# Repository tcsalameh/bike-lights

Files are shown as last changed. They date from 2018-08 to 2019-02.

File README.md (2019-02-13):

## Speed-sensitive bike lights

This is a project I did to create side-mounted lights for my commuter bike that would react to different speeds.

You can see them in action in the short video below!

video (https://www.youtube.com/watch?v=7HX3JH0OVps)

## Hardware Design

An LED light strip covers both sides of the bike, going up the downtube (the bottom part of the frame), around the front of the headtube (the front part of the frame above the wheel), and back down the downtube on the other side.

The computer (an Arduino Uno) and battery sit inside a re-purposed water bottle container attached to the seat tube (the middle part of the frame). A [Hall sensor chip](https://en.wikipedia.org/wiki/Hall_effect_sensor) installed on one of the seat stays (the back lower part of the frame) records whenever a magnet attached to one of the spokes passes by. The computer uses this data to measure speed, so it can determine what to display on the light strip.

I also wanted to be able to easily detach the whole system from my bike, in about 5 minutes or less. The light strip and sensor cabling can detach from the power/computer container, and the whole system is secured with velcro to the frame. I've been able to take it on and off, and even stick it in a backpack, without too much trouble.

Battery life is quite long.
From the numbers [here](https://learn.adafruit.com/battery-power-for-led-pixels-and-strips/estimating-running-time), each "pixel" of 3 LEDs has a max power consumption of 60 mAh.
I guessed the battery pack had approximately 3000-4000 mAh based on https://en.wikipedia.org/wiki/AA_battery#Rechargeable_cells.
Eight pixels are on at a time, so even if they were running at max brightness, I would expect something in the range of 5-7 hours battery life, taking extra power needed for the other components into account.
The pixels are typically nowhere near the max brightness, so this might even be a low estimate.
Empirically, I've been able to leave it on for hours at a time with no visible effect on LED brightness.

The battery capacity is far more than I need. If I were to make another iteration, I would look at 3d printing the case and select a smaller form factor for the computer and power supply.
I would also rethink the placement of the cables, the velcro system (would be nice not to have to glue velcro to the frame), and the minimal protection from the elements.

## Software Design

I kept this project simple, with less than 300 lines of code.
However, I have plans to experiment with external graphical interfaces to simulate and update the system, which would make it a lot more complex.

The Arduino Uno is a single-threaded, single core computing platform that just runs the code you provide in a tight loop over and over.
This posed a challenge for simultaneously keeping track of the speed and updating the light strip.
Although the Arduino Uno does not have genuine threads, you can use a number of pseudo-threading libraries (I used [ArduinoThread](https://github.com/ivanseidel/ArduinoThread)). These give the appearance of multi-tasking by only executing the work given to the thread at a set interval, and doing a no-op any other time the thread is called. If you have 2+ tasks that don't have to run on every loop and they do fairly lightweight work, then setting them to run at different intervals, faster than a human would typically notice, can give the appearance of simultaneity.

Updating the light strip and keeping track of the speed fit this use case well. The light strip is idle most of the time except during transition, and it isn't crucial that we calculate the speed at every millisecond. I implemented two pseudo-threads running callbacks on separate time intervals: A light strip updating thread, and a speed updating thread. I discovered it was important to execute the actual sensor reads in every loop, because it is easy to miss a read at high speed. So, that action occurs outside of the thread context in loop().

I also wanted the speed data to inform the frequency of the light strip update operation. This turned out to be fairly simple: The light strip thread gets the latest speed from the speed thread, and then updates its own callback frequency based on this data.

Lastly, I had fun working out different ways to change the lightstrip along color gradients. I ended up settling on a linear gradient to move between RGB values, but I'm sure there are all kinds of other interesting algorithms to explore (maybe I should study some color theory!).

## Parts

- 1 Arduino Uno
- 1 4AA battery holder (https://www.amazon.com/LAMPVPATH-Battery-Connector-Plastic-Housing/dp/B01MAXT00Q/)
- 4 rechargable AA batteries. Note: The rechargable part is important! Alkaline batteries will have a higher voltage. 4AA rechargable is ~4.8V, close enough to 5V to power the whole system without issue. 4AA alkaline is ~6V, above the safe voltage for the light strip.
- 1 toggle switch (https://www.adafruit.com/product/3308)
- 1 Hall sensor chip (https://www.amazon.com/SunFounder-Switch-Sensor-Arduino-Raspberry/dp/B013G5N03O/)
- 1 spoke magnet (https://www.amazon.com/CatEye-Universal-Wheel-Magnet/dp/B018RZ23AE/)
- 1 470-ohm resistor
- 1 large capacitor (I used the 4700uF model found here: https://www.adafruit.com/product/1589)
- 1 Neopixel light strip, 60 pixels per strip (https://www.adafruit.com/product/1461?length=1)
- 2 4-wire waterproof cables (https://www.adafruit.com/product/744)
- 1 mid-size water bottle storage container (or even just a water bottle). Main limiting factor here is whether the Arduino can fit through the mouth of the bottle. I used the WBS Unit from Profile Design, it was just barely big enough to fit everything (https://www.amazon.com/Profile-Designs-Water-Bottle-Storage/dp/B01E6EZNW0/).
- Adhesive velcro strips, and some velcro ties
- Some sticky pads for wall hangings (relevant for padding the sensor if you need to get it closer to the wheel)
- Lots of colored hook up wire, shrink wrap, superglue, etc.

## Wiring Diagram

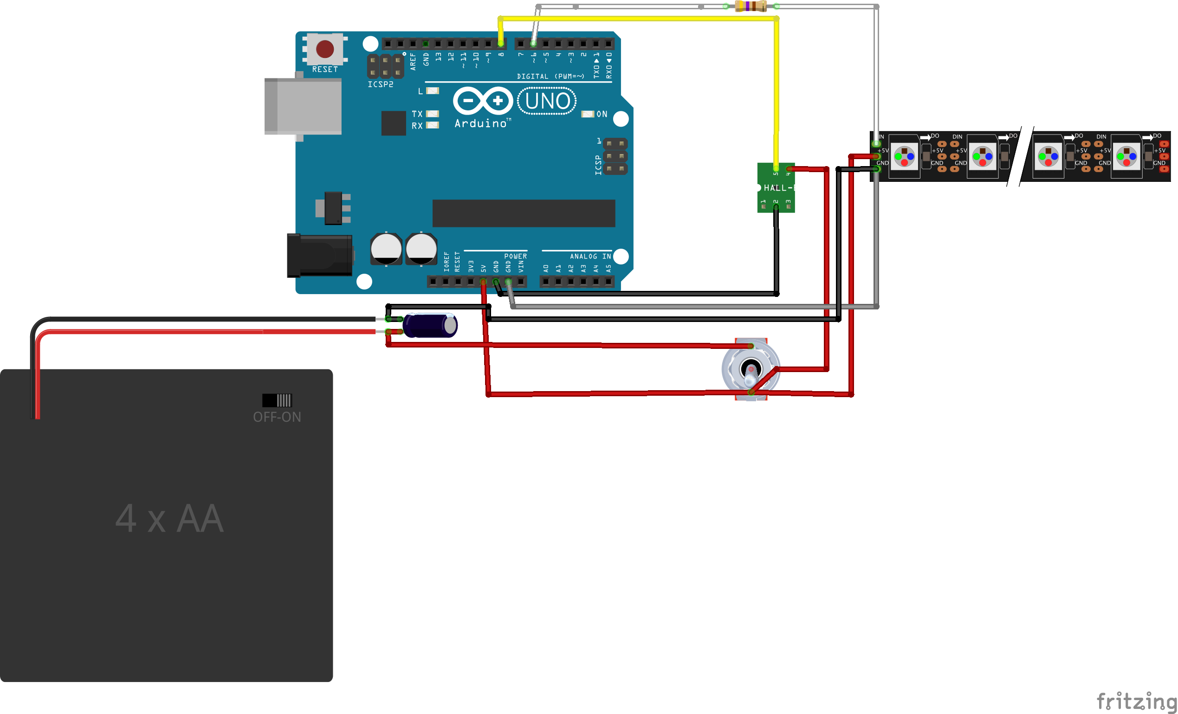
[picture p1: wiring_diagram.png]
Wiring Diagram


## How to make it

1. I wired up and got the whole system working without trying to put anything other than the light strip on the bike. Only after I was satisfied that the code/hardware actually worked, did I think about how it was going to get attached.
1. Then, I took the water bottle storage container and drilled 3 holes - one just above where the cage would end for the toggle switch, and two in the bottom of the container (for cables for the light strip and the Hall sensor).
1. Then, I broke out the soldering iron and started with where the 4 wire cables would end: at the light strip and at the sensor.
      - Soldered the 4 wires to power, data, ground, and ground wires from the LED strip. I lost the threaded connector for the cable during this process.
      - For the other one, cut off one wire and soldered the remaining to power, data, and ground wires of the Hall sensor.
1. Then, I started from the other end and connected the power supply to the toggle switch, and soldered wires going into and out of the switch.
1. At this point I really wanted to be sure that everything was right, because once I soldered any of the 7 wires from the cables to the Arduino or output of the switch, I wouldn't be able to dissasemble anything without de-soldering most of it.
1. After making sure, I soldered all the remaining connections, which was a bit tricky since everything was half in the container. Since the power/ground wires going to the Arduino were so close, I put some glue in between them after soldering the wires to the header pins, as insulation.
1. Then I attempted to stuff everything into the storage container. It took some wrangling, but the container was just barely large enough to fit everything. I'd originally planned to somehow mount the Arduino and battery pack in there to prevent rattling around, but they fit pretty snugly anyhow. The battery pack is easy to remove for recharging, and the USB port on the Arduino is easily accessible for reprogramming.
1. Finally, I worked on mounting the sensor to the back left chainstay, near the wheel. I used a small piece of an adhesive velcro strip to attach it, and found that I needed to put some padding on the back of the sensor to get it close enough to the wheel. Using adhesive wall hanging strips added about 10-20 millimeters, more than enough. I forgot to put a cover over the sensor before attaching the Velcro, so it is exposed to the elements (and I will probably need to replace it). Strategically placed velcro ties keep all the cables from straying too far from the frame.

## More Pictures and Videos

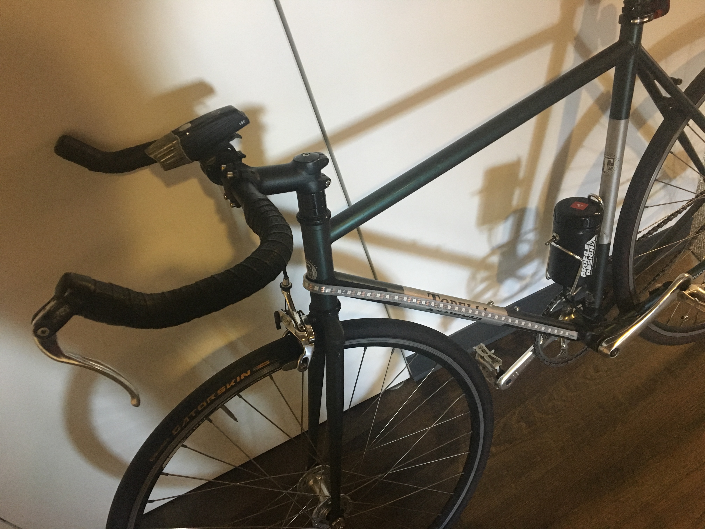
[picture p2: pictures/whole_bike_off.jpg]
bike

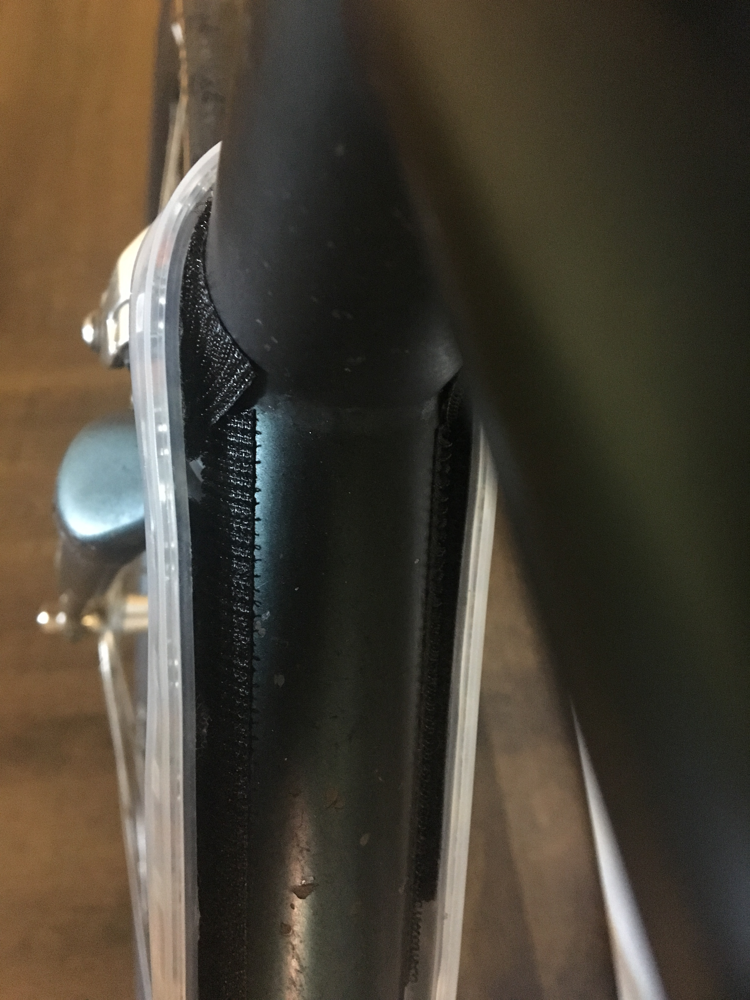
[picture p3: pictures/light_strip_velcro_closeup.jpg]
led_velcro

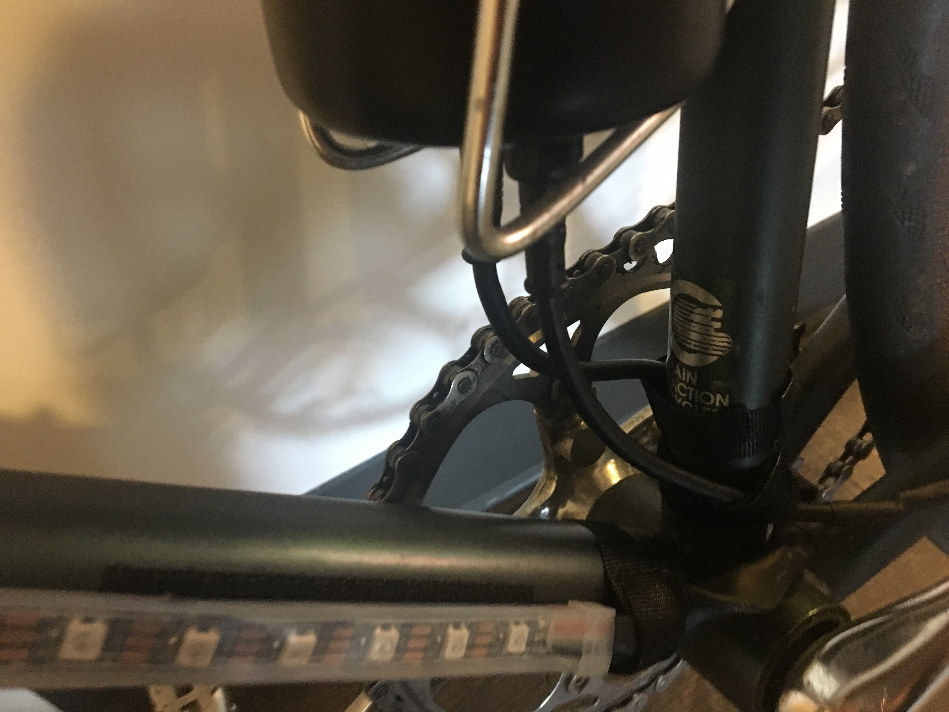
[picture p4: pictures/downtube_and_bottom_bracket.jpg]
downtube_bb

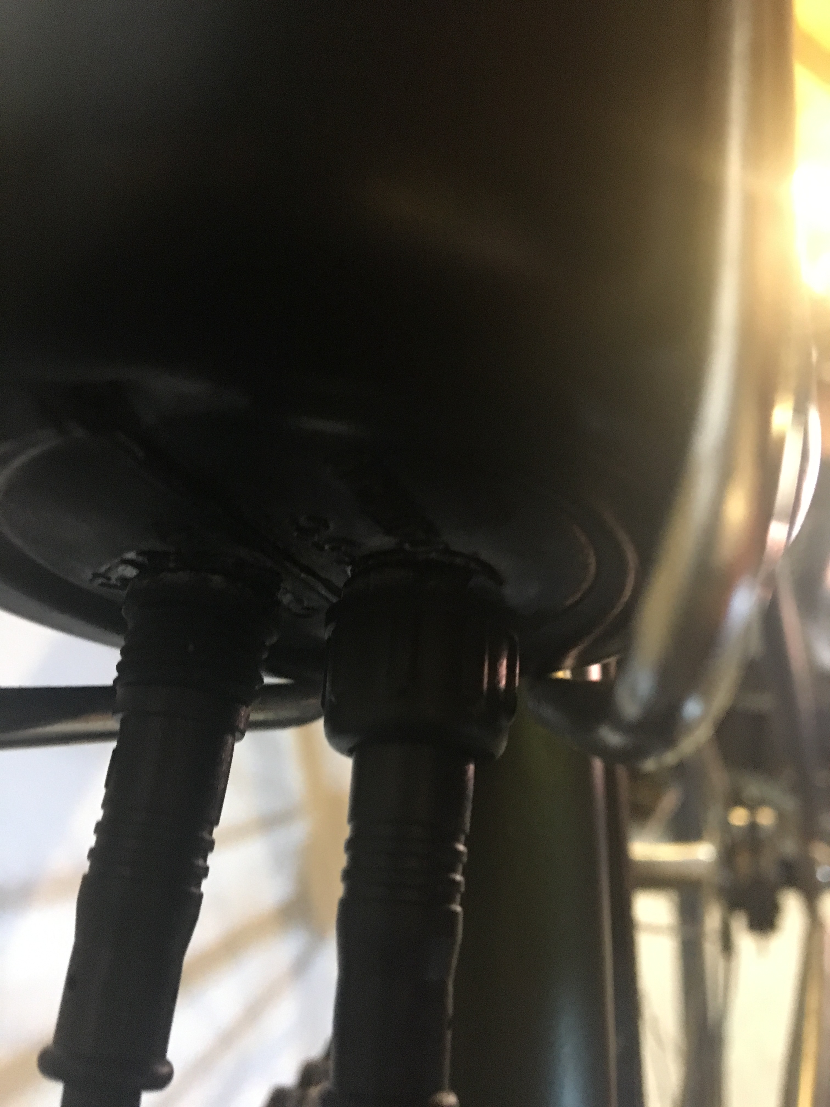
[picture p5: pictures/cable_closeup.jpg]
cable_closeup

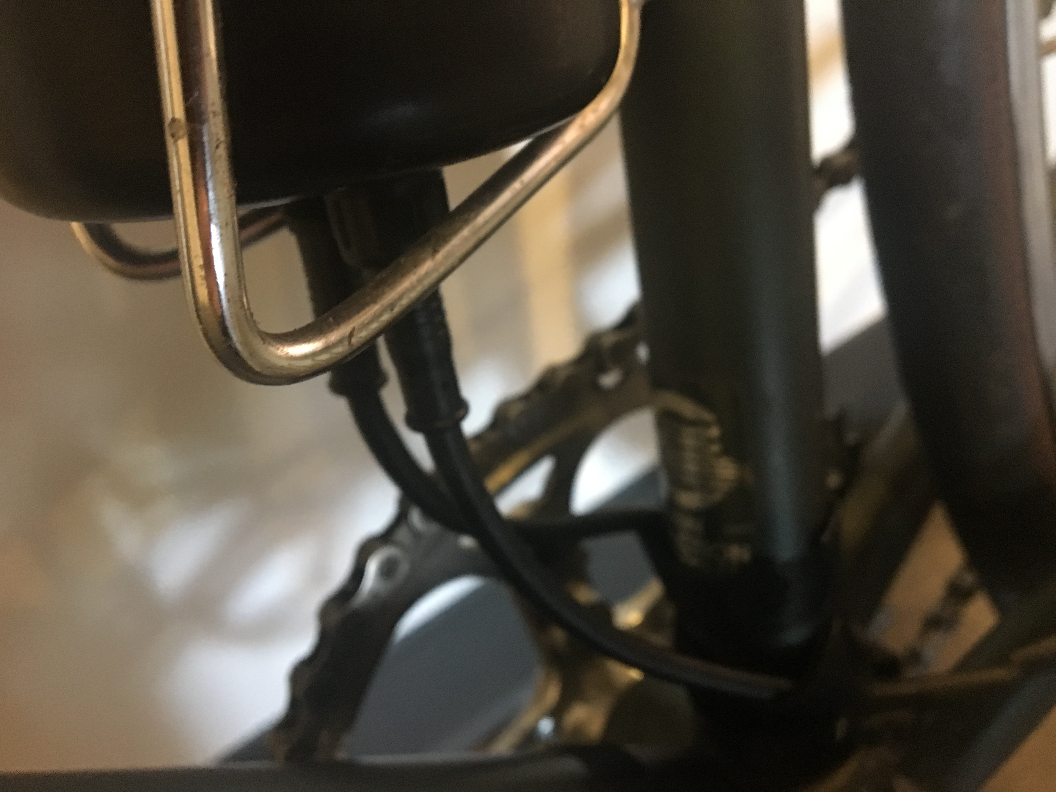
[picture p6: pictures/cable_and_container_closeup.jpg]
cable_and_container_closeup

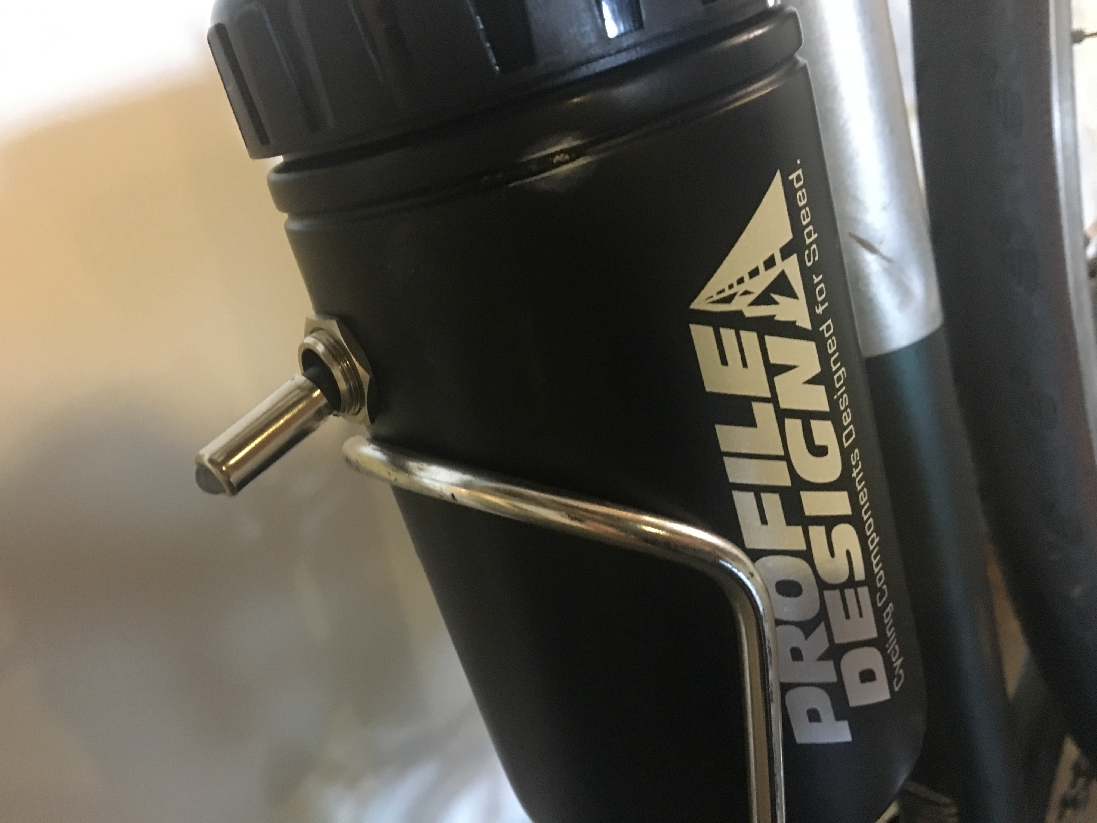
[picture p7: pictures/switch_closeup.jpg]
switch_closeup

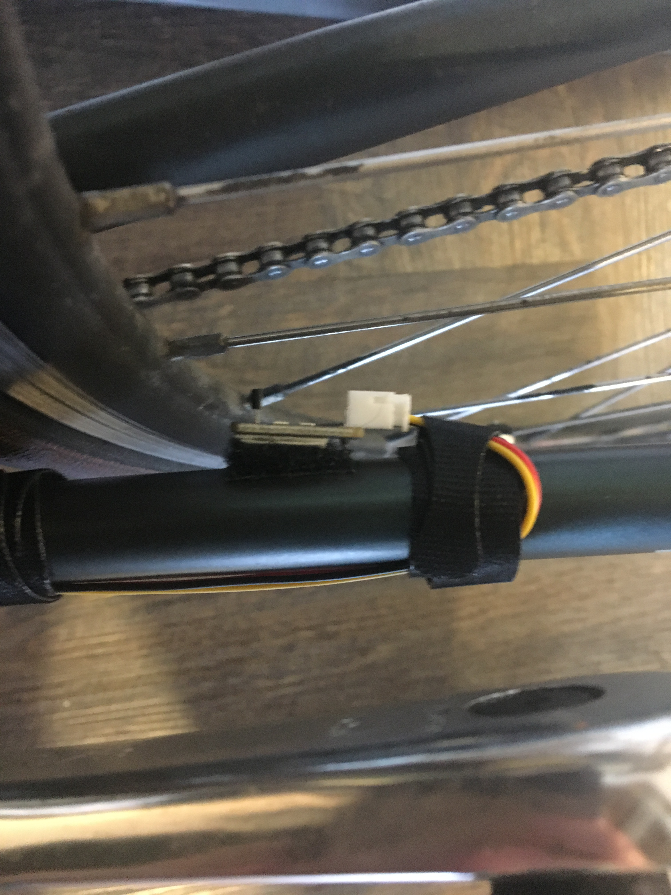
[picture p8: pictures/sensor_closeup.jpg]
sensor_closeup

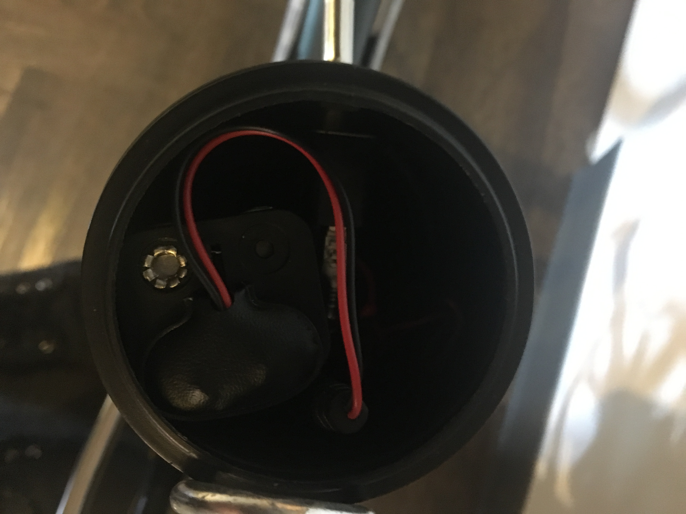
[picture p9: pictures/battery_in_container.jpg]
open_container

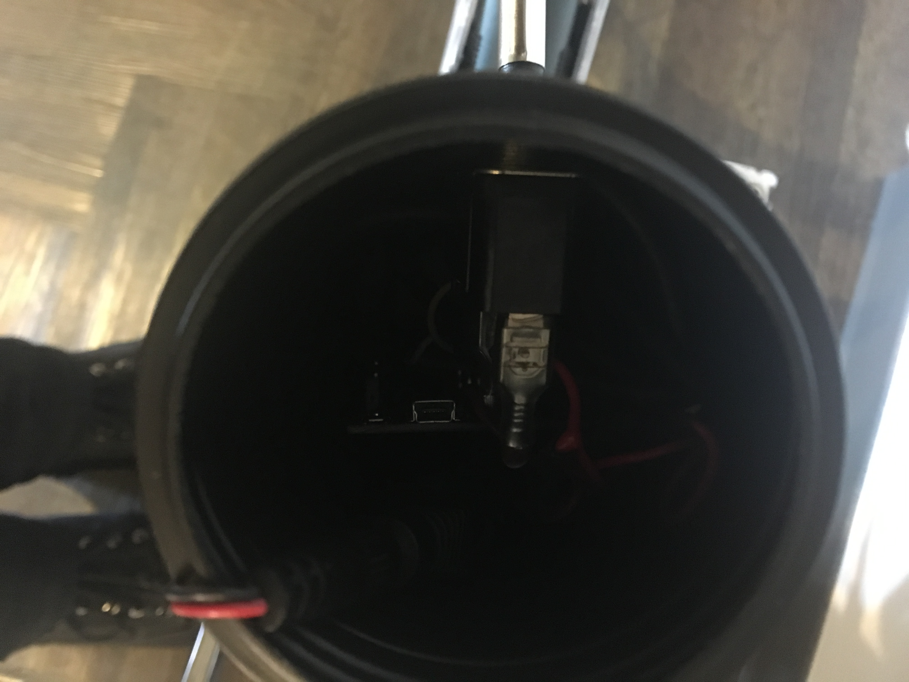
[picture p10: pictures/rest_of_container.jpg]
open_container_no_battery


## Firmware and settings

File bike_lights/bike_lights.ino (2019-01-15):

/*
This code will animate a "caterpillar" style of light display.
Lights will start in a line of PIX_PER_RUN pixels, and "crawl" up
towards the headtube, starting again at the bottom of the downtube.

The rate at which the lights "crawl" changes depending on how fast the
wheel is rotating. Maximum and minimum values can be configured.

The color of the lights also changes depending on speed, and maximum and
minimum colors can be selected. The lights will step through a smooth range
of intermediate colors as speed increases until they reach the maximum.
*/

#include <StaticThreadController.h>
#include <Thread.h>
#include <ThreadController.h>
#include <Adafruit_NeoPixel.h>

#define PIXEL_PIN    6
#define SENSOR_PIN   8
#define STRIP_SIZE   68    // number of pixels in light strip
#define PIX_PER_RUN  3     // number of pixels in "caterpillar"

#define COLOR_ROT_TIME_MIN  75      // milliseconds between wheel rotations below which we're at the fastest color
#define COLOR_ROT_TIME_MAX  1275    // milliseconds between wheel rotations below which we're at teh slowest color

#define R_COLOR_MIN      255    // red value at slowest speed
#define G_COLOR_MIN      0      // green value at slowest speed
#define B_COLOR_MIN      0      // blue value at slowest speed
#define R_COLOR_MAX      0      // red value at fastest speed
#define G_COLOR_MAX      255    // green value at fastest speed
#define B_COLOR_MAX      100    // blue value at fastest speed
#define R_RANGE          (double) (R_COLOR_MAX - R_COLOR_MIN)    // total range of red values
#define G_RANGE          (double) (G_COLOR_MAX - G_COLOR_MIN)    // total range of green values
#define B_RANGE          (double) (B_COLOR_MAX - B_COLOR_MIN)    // total range of blue values

#define RATE_ROT_TIME_MIN   51     // milliseconds between wheel rotations below which we're at the fastest change rate
#define RATE_ROT_TIME_MAX   4000   // milliseconds between wheel rotations above which we're at the slowest change rate
#define RATE_MIN            10     // minimum number of milliseconds between transitions
#define RATE_MAX            400    // maximum number of milliseconds between transitions
#define RATE_RANGE          (double) (RATE_MAX - RATE_MIN)    // total range of transition rate values

#define STOPPED          2000    // if wheel rotation takes more milliseconds than this, we consider the bike stopped
#define R_STOPPED        255     // red value when we're stopped
#define G_STOPPED        0       // green value when we're stopped
#define B_STOPPED        0       // blue value when we're stopped
#define STOPPED_RATE     400     // milliseconds between animation transition when we're stopped

class PixelThread: public Thread {
/* Class to encapsulate the thread controlling a light strip */
  public:
    Adafruit_NeoPixel strip;
    uint8_t pix_per_run;    // number of pixels in "caterpillar"
    uint16_t index;
    uint32_t color;

    PixelThread(
      Adafruit_NeoPixel _strip,
      uint8_t _pix_per_run
    ) {
      strip = _strip;
      pix_per_run = _pix_per_run;
      index = 0;
      color = strip.Color(255, 0, 0);
    }

    uint32_t calculateColor(long rotation_time) {
      /* This function calculates what color the pixels
      should be based on the number of milliseconds one wheel
      revolution takes. It finds where the rotation time falls
      between our minimum and maximum rotation times, translates
      that into a percentage, and then uses the percentage to
      calculate how far between min and max each RGB component should
      lie. */
      double pctg;

      if (rotation_time >= STOPPED)
        return strip.Color(R_STOPPED, G_STOPPED, B_STOPPED);

      pctg = abs(rotation_time - COLOR_ROT_TIME_MAX) / (double) (COLOR_ROT_TIME_MAX - COLOR_ROT_TIME_MIN);
      if (pctg < 0)
        pctg = 0.0;
      if (pctg > 1)
        pctg = 1.0;

      return strip.Color(
          R_COLOR_MIN + (uint8_t) (pctg * R_RANGE),
          G_COLOR_MIN + (uint8_t) (pctg * G_RANGE),
          B_COLOR_MIN + (uint8_t) (pctg * B_RANGE)
        );
    }
};

class SpeedThread: public Thread {
/* Class to encapsulate a thread that measures the time of each wheel rotation */
  public:
    uint16_t rate;    // the update rate we will calculate for the animation
    long rotation_time;

    long _timeOfLastHit;
    long _timeSinceLastRotation;
    bool _reset;

  SpeedThread() {
    rate = 300;
    rotation_time = 4000;
    _timeSinceLastRotation = 5000;
    _timeOfLastHit = 0;
    _reset = false;
  }

  void updateRotation() {
  /* updates the time since the last rotation,
  should be called in a tight loop */
    if (_reset) {
      _reset = (digitalRead(SENSOR_PIN) == LOW);
      return;
    }
    if ((digitalRead(SENSOR_PIN) == LOW) && (millis() - _timeOfLastHit > 100)) {
      _timeSinceLastRotation = millis() - _timeOfLastHit;
      _timeOfLastHit = millis();
      _reset = true;
    }
  }

  uint16_t calculateRate() {
  /* Based on the milliseconds it takes the wheel to rotate,
  calculates the number of milliseconds between animation updates.
  It maps the rotation time linearly against the min and max rates. */
    double pctg;

    if (rotation_time >= STOPPED)
      return STOPPED_RATE;

    pctg = abs(rotation_time - RATE_ROT_TIME_MIN) / (double) (RATE_ROT_TIME_MAX - RATE_ROT_TIME_MIN);
    if (pctg < 0)
      pctg = 0.0;
    if (pctg > 1)
      pctg = 1.0;

    return RATE_MIN + (uint16_t) (pctg * RATE_RANGE);
  }

  void setRate() {
  /* callback to periodically calculate rate, should be called
  more frequently than the fastest rotation time */
    rotation_time = max(_timeSinceLastRotation, millis() - _timeOfLastHit);
    rate = calculateRate();
  }
};


// Parameter 1 = number of pixels in strip
// Parameter 2 = Arduino pin number (most are valid)
// Parameter 3 = pixel type flags, add together as needed:
//   NEO_KHZ800  800 KHz bitstream (most NeoPixel products w/WS2812 LEDs)
//   NEO_KHZ400  400 KHz (classic 'v1' (not v2) FLORA pixels, WS2811 drivers)
//   NEO_GRB     Pixels are wired for GRB bitstream (most NeoPixel products)
//   NEO_RGB     Pixels are wired for RGB bitstream (v1 FLORA pixels, not v2)
//   NEO_RGBW    Pixels are wired for RGBW bitstream (NeoPixel RGBW products)
Adafruit_NeoPixel strip = Adafruit_NeoPixel(STRIP_SIZE, PIXEL_PIN, NEO_GRB + NEO_KHZ800);
PixelThread pt = PixelThread(strip, PIX_PER_RUN);
SpeedThread st = SpeedThread();

ThreadController controller = ThreadController();

void speedCallback() {
  st.setRate();
}

void lightStripCallback() {
/* Callback to update the light strip.
Clears the last pixel in the "caterpillar",
and fills in the next pixel ahead. */
  uint16_t n = strip.numPixels();
  if (pt.index > 0) {
    strip.setPixelColor(pt.index-1, 0);
    strip.setPixelColor(n - pt.index, 0);
  }
  uint32_t c = pt.calculateColor(st.rotation_time);
  for (uint16_t j=pt.index; j<(pt.index + pt.pix_per_run); j++) {
    strip.setPixelColor(j, c);
  }
  for (uint16_t l=(n-pt.index-1); l>=(n-pt.index-pt.pix_per_run); l--) {
    strip.setPixelColor(l, c);
  }
  if (pt.index <= ((n / 2) - pt.pix_per_run)) {
    pt.index++;
  } else {
    for (uint16_t k=pt.index; k<(n / 2) - 1; k++) {
      strip.setPixelColor(k, 0);
    }
    for (uint16_t x=(n-pt.index-1); x>(n / 2); x--) {
      strip.setPixelColor(x, 0);
    }
    pt.index = 0;
  }
  strip.show();

  pt.setInterval(st.rate);
}


void setup() {
  pinMode(SENSOR_PIN, INPUT);
  strip.begin();
  strip.show();

  pt.onRun(lightStripCallback);
  pt.setInterval(50);

  st.onRun(speedCallback);
  st.setInterval(201);

  controller.add(&pt);
  controller.add(&st);
}

void loop() {
  // Rather than explicitly calling as another pseudo-thread,
  // found it more effective to recalculate rotation rate on every loop.
  st.updateRotation();
  controller.run();
}

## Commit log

2018-08-14 Decrease rate adjustment factor from 15 to 5
    This has the effect of increasing the wait time.
    I did this because I was hitting the higher colors at too low speeds.
    However, I think the wait time is still too low. Will want to rethink
    the color and rate determination algorithm down the road.
    [bike_lights.ino]
2018-08-17 Add fritzing wiring diagram
    [wiring_diagram.fzz]
2018-08-17 Add README with wiring diagram and parts list
    [wiring_diagram.fzz]
2018-08-17 Update README with power supply addition
2018-08-17 Fix formatting, add details about cable connector
2019-01-15 refactor Arduino code to pull out magic numbers
    - pull out magic numbers into define statements
    - rewrite functions for rate and color transitions to be parameterizable
    - remove "flashing when stopped" functionality
2019-01-15 move Arduino source into separate directory
2019-02-13 Overhaul README, provide more design context (#2)
    * Overhaul README, provide more design context
    - Add hardware and software design sections
    - Update parts list
    - Fix typos
    * Add link to Hall sensor wiki, capitalize Hall
